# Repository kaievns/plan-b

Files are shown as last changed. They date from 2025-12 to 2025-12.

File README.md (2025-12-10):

# Plan B

This is a tiny opinionated PCB that has everything packed in one place for
creating split bluetooth keyboards on top of nrf52840 chip and ZMK firmware

Think about it as

- an improved nice!nano clone in a smaller package
- has baked nice!view inside with a slot for LCD
- has baked in RGB controller
- has baked in 6-pin SPI interface for external sensor
- has baked in wiring for 6x6 keyboard matrix via JST connectors
- has baked in power/reset switches for both sides
- high efficiency DC/DC buck converters for all power lines
- heavily fabrication optimised BOM and PCB (est $130 per 5 units at JLCPCB)

All in a tiny 14x42mm package, which is about 8m longer than nice!view shield

<p align="center">
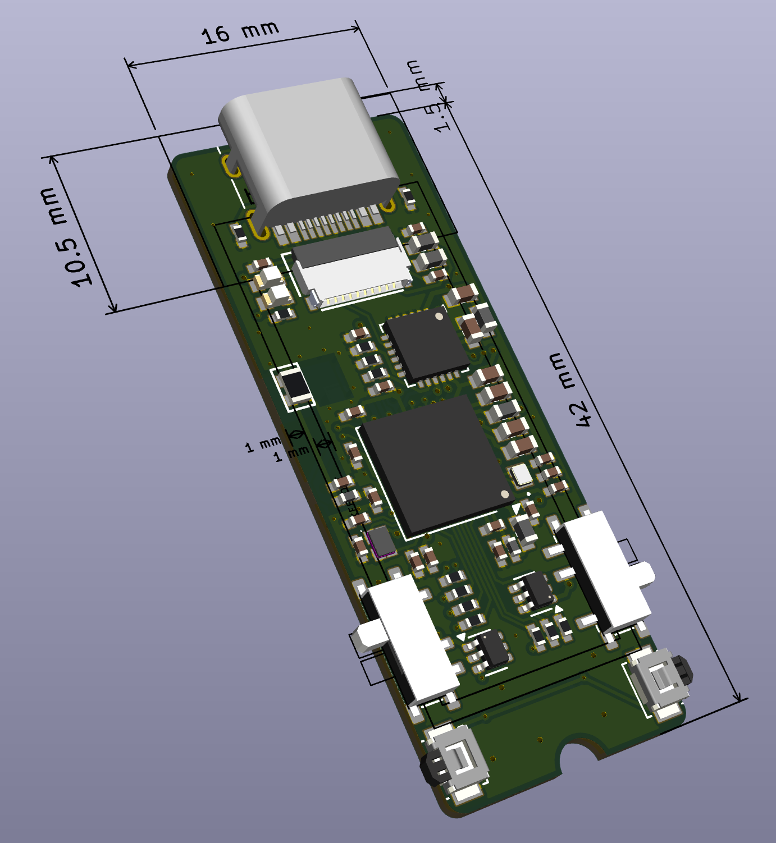
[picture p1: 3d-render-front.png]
PCB Front
  
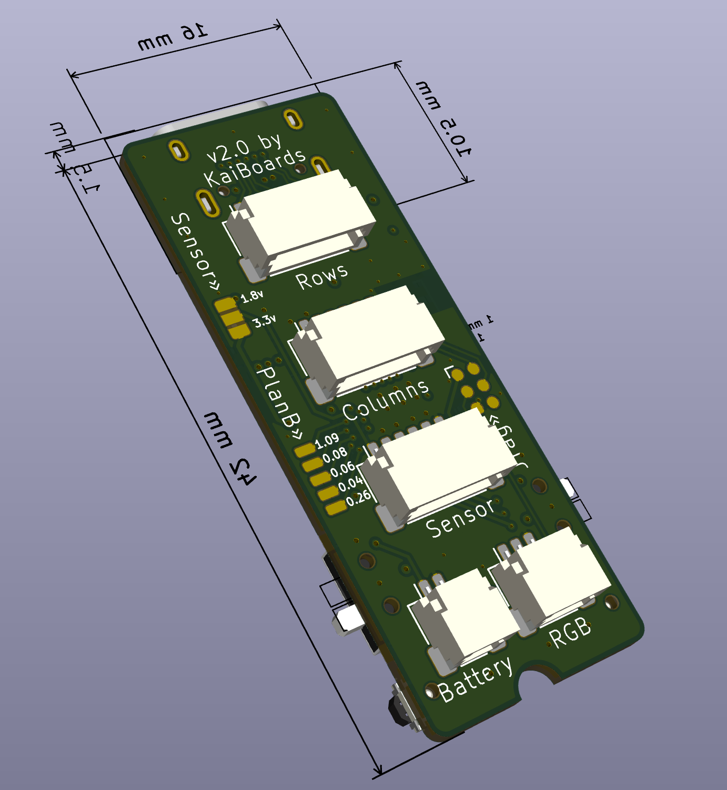
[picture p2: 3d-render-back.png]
PCB Back
  
</p>

## Copyright & License

Everything is released under the terms of the CC BY-SA 4.0 license

© 2025 Kai Evans

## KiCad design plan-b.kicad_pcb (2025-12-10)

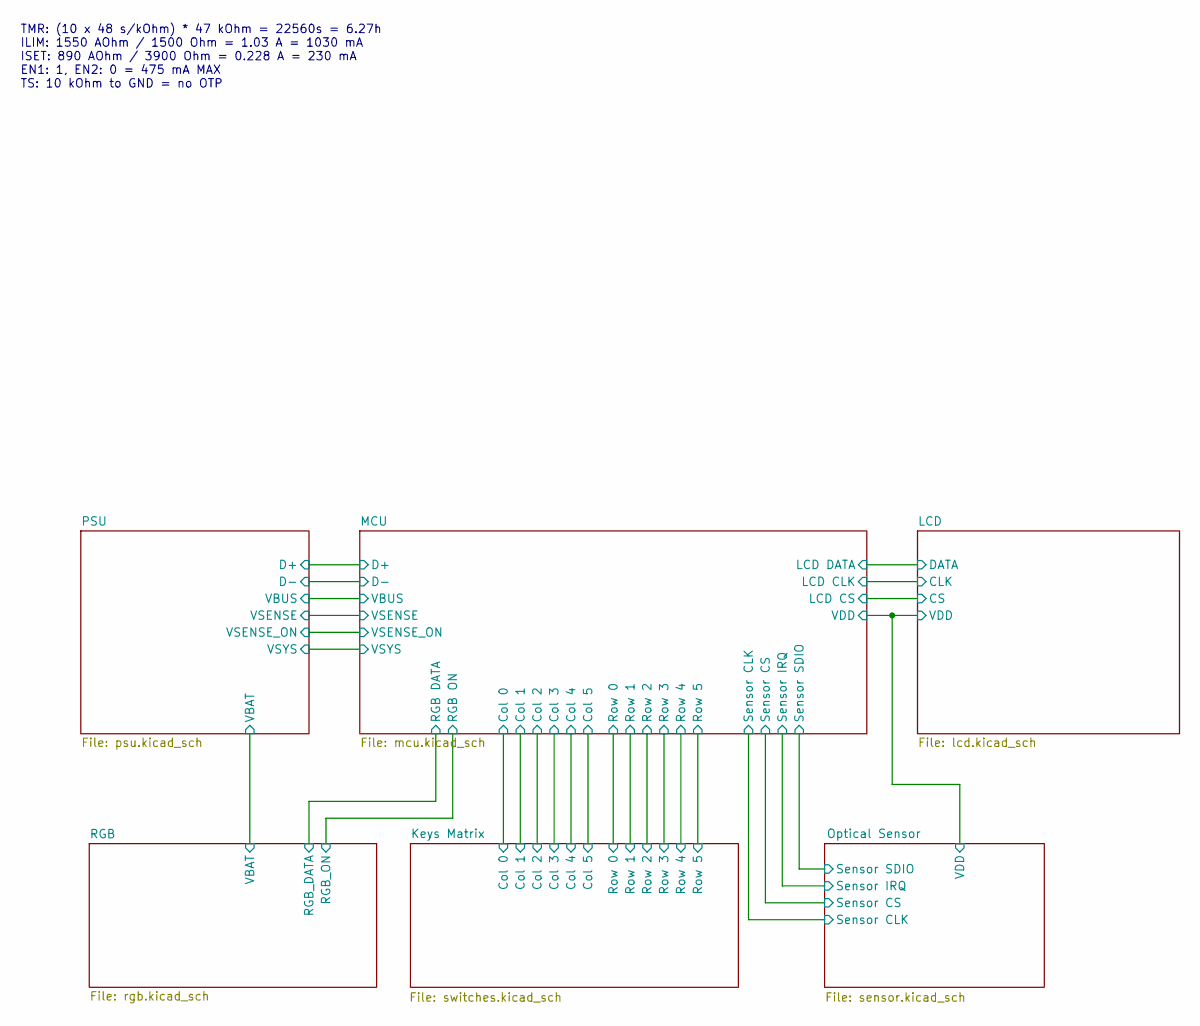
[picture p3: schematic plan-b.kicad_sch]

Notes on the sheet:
TMR: (10 x 48 s/kOhm) * 47 kOhm = 22560s = 6.27h ILIM: 1550 AOhm / 1500 Ohm = 1.03 A = 1030 mA ISET: 890 AOhm / 3900 Ohm = 0.228 A = 230 mA EN1: 1, EN2: 0 = 475 mA MAX TS: 10 kOhm to GND = no OTP

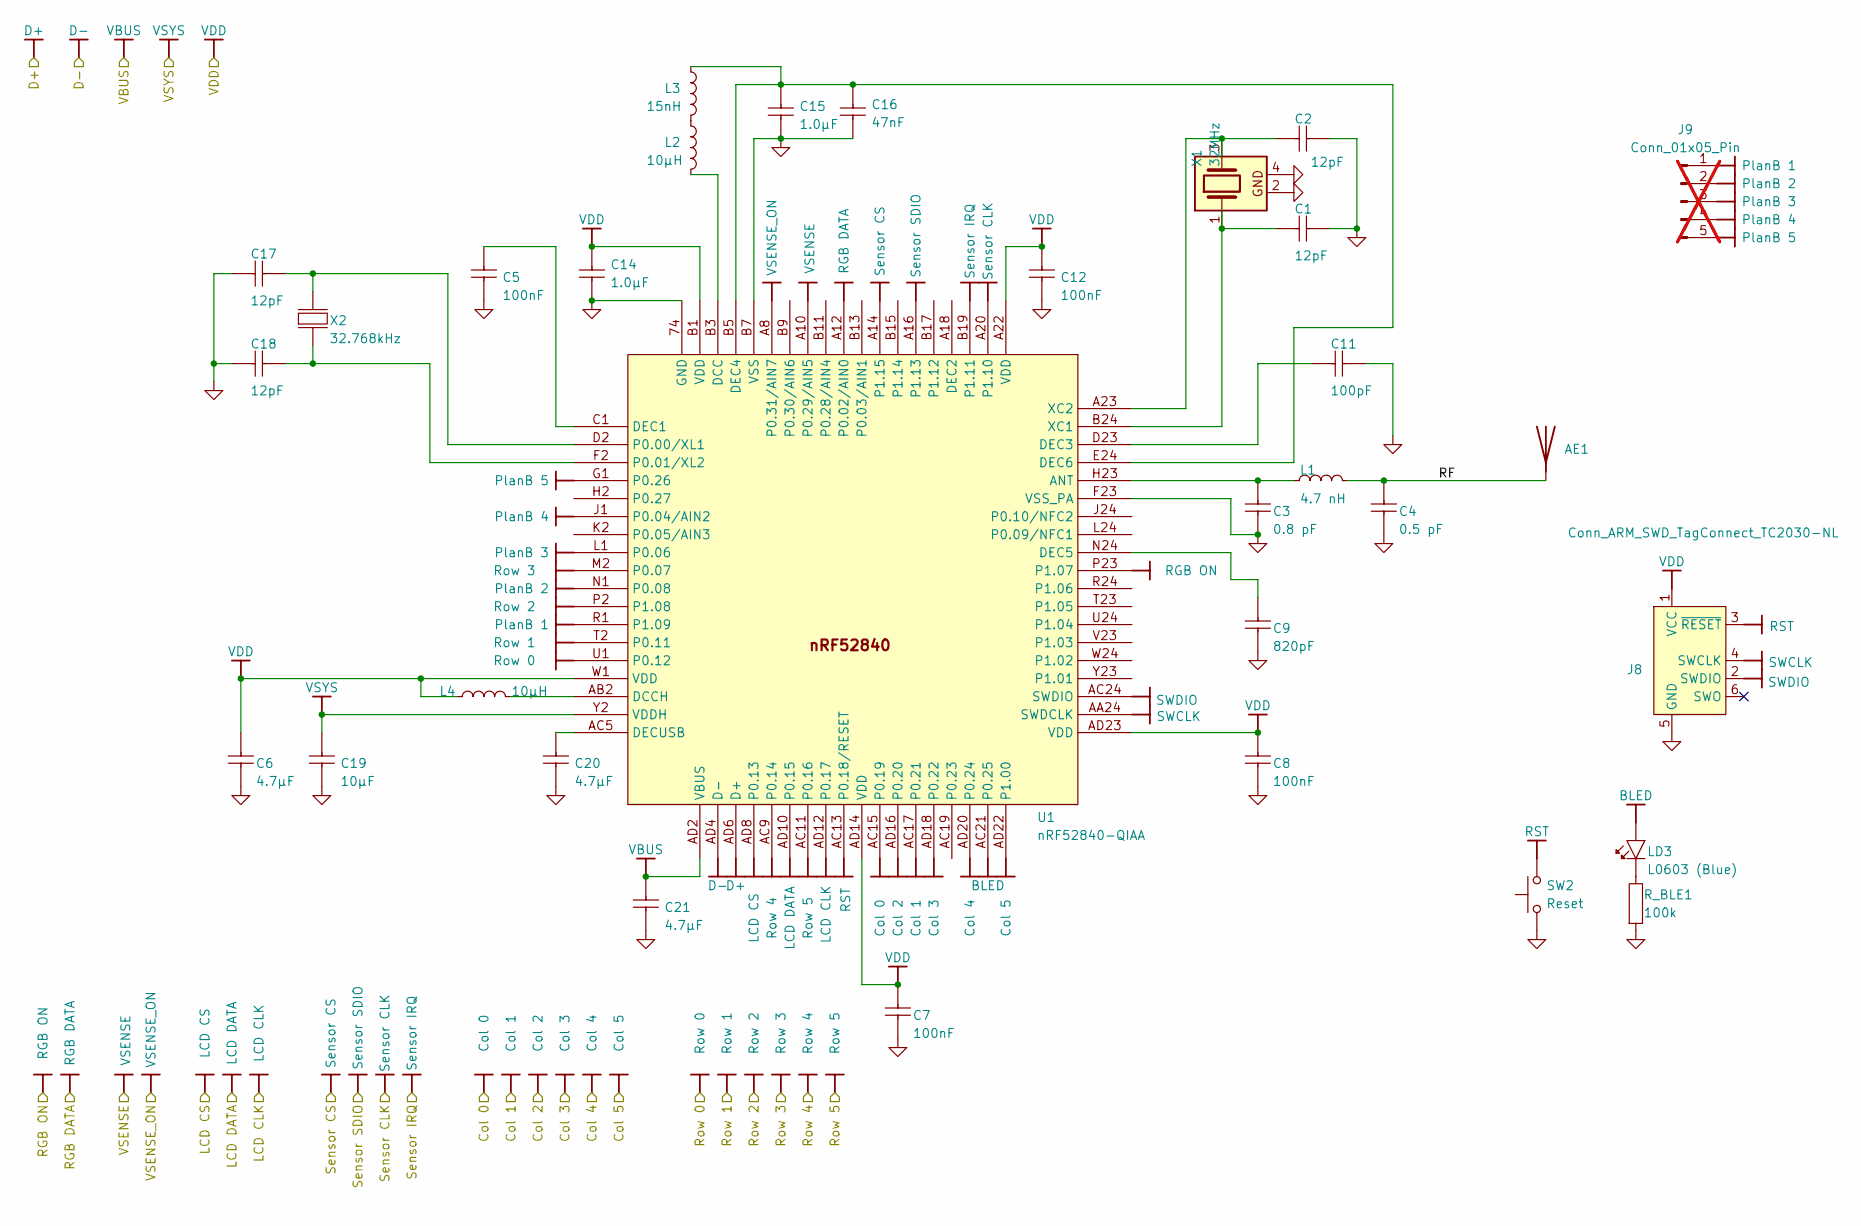
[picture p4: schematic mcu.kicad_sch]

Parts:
AE1: ANT2012LL13R2400A; PARTREV 1.3; LCSC C19192917
C1, C2, C17, C18: 12pF; C_0402_1005; PART NUMBER C0402-12p; LCSC C1547
C3: 0.8 pF; C_0402_1005; PART NUMBER C0402-0.8p; LCSC C40459
C4: 0.5 pF; C_0402_1005; PART NUMBER C0402-0.8p; LCSC C76912
C5, C7, C8, C12: 100nF; C_0402_1005; PART NUMBER C0402-100n; LCSC C1525
C6, C20: 4.7µF; C_0603_1608; PART NUMBER C0603-4µ7-6.3V-X7R; LCSC C1624
C9: 820pF; C_0402_1005; PART NUMBER C0402-100n; LCSC C107031
C11: 100pF; C_0402_1005; PART NUMBER C0402-100p; LCSC C1546
C14, C15: 1.0µF; C_0402_1005; PART NUMBER C0603-1µ0; LCSC C52923
C16: 47nF; C_0402_1005; PART NUMBER C0402-47n; LCSC C82219
C19: 10µF; C_0603_1608; PART NUMBER C0603-4µ7-10V-X7S; LCSC C19702
C21: 4.7µF; C_0603_1608; PART NUMBER C0603-4µ7-10V-X7S; LCSC C1624
J8: Conn_ARM_SWD_TagConnect_TC2030-NL; Tag-Connect_TC2030-IDC-NL_2x03_P1.27mm_Vertical
J9: Conn_01x05_Pin; JST_SHL_SM05B-SHLS-TF_1x05-1MP_P1.00mm_Horizontal; not fitted
L1: 4.7 nH; L_0402_1005; PART NUMBER L0402-4n7; LCSC C86065
L2, L4: 10µH; L_0603_1608; PART NUMBER L0603-10µ; LCSC C1035
L3: 15nH; L_0402_1005; PART NUMBER L0402-15n; LCSC C86059
LD3: L0603 (Blue); LED_0603_1608; LCSC C84266
R_BLE1: 100k; R_0402_1005; LCSC C25741
SW2: Reset; SW_SPST_B3U-3000P-B; LCSC C963349
U1: nRF52840-QIAA; Nordic_AQFN-73-1EP_7x7mm_P0.5mm; PART NUMBER nRF52840-QIAA; LCSC C1851953
X1: 32MHz; OSCSC105P160X120X35-4N; PART NUMBER XTAL_SMD2016_32MHz_8pF_General; LCSC C910049
X2: 32.768kHz; XTAL_ECS32761210TR; PART NUMBER XTAL_SMD3215_32.768kHz_9pF_General; LCSC C5682932

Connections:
/MCU/RF: AE1.1 (A), C4.2, L1.2
BLED: LD3.2 (A), U1.AC21 (P0.25)
CLK: U1.AD12 (P0.17); also elsewhere on the board
CS: U1.AD8 (P0.13); also elsewhere on the board
Col 0: U1.AC15 (P0.19); also elsewhere on the board
Col 1: U1.AC17 (P0.21); also elsewhere on the board
Col 2: U1.AD16 (P0.20); also elsewhere on the board
Col 3: U1.AD18 (P0.22); also elsewhere on the board
Col 4: U1.AD20 (P0.24); also elsewhere on the board
Col 5: U1.AD22 (P1.00); also elsewhere on the board
D+: U1.AD6 (D+); also elsewhere on the board
D-: U1.AD4 (D-); also elsewhere on the board
DATA: U1.AD10 (P0.15); also elsewhere on the board
GND: C1.2, C2.2, C3.1, C4.1, C5.2, C6.2, C7.2, C8.2, C9.2, C11.2, C12.2, C14.2, C15.1, C16.2, C17.2, C18.2, C19.2, C20.2, C21.2, J8.5 (GND), R_BLE1.2, SW2.1, U1.74 (GND), U1.B7 (VSS), U1.F23 (VSS_PA), X1.2, X1.4; also elsewhere on the board
unnamed: L2.1, L3.2
unnamed: LD3.1 (C), R_BLE1.1
unnamed: C3.2, L1.1, U1.H23 (ANT)
unnamed: L2.2, U1.B3 (DCC)
unnamed: L4.2, U1.AB2 (DCCH)
unnamed: C5.1, U1.C1 (DEC1)
unnamed: C11.1, U1.D23 (DEC3)
unnamed: C15.2, C16.1, L3.1, U1.B5 (DEC4), U1.E24 (DEC6)
unnamed: C9.1, U1.N24 (DEC5)
unnamed: C20.1, U1.AC5 (DECUSB)
unnamed: C17.1, U1.D2 (P0.00/XL1), X2.1 (inp)
unnamed: C18.1, U1.F2 (P0.01/XL2), X2.2 (out)
unnamed: C1.1, U1.B24 (XC1), X1.1
unnamed: C2.1, U1.A23 (XC2), X1.3
PlanB 1: J9.1, U1.R1 (P1.09)
PlanB 2: J9.2, U1.N1 (P0.08)
PlanB 3: J9.3, U1.L1 (P0.06)
PlanB 4: J9.4, U1.J1 (P0.04/AIN2)
PlanB 5: J9.5, U1.G1 (P0.26)
RGB DATA: U1.A12 (P0.02/AIN0); also elsewhere on the board
RGB ON: U1.P23 (P1.07); also elsewhere on the board
RST: J8.3 (~RESET), SW2.2, U1.AC13 (P0.18/RESET); also elsewhere on the board
Row 0: U1.U1 (P0.12); also elsewhere on the board
Row 1: U1.T2 (P0.11); also elsewhere on the board
Row 2: U1.P2 (P1.08); also elsewhere on the board
Row 3: U1.M2 (P0.07); also elsewhere on the board
Row 4: U1.AC9 (P0.14); also elsewhere on the board
Row 5: U1.AC11 (P0.16); also elsewhere on the board
SWCLK: J8.4 (SWCLK), U1.AA24 (SWDCLK)
SWDIO: J8.2 (SWDIO), U1.AC24 (SWDIO)
Sensor CLK: U1.A20 (P1.10); also elsewhere on the board
Sensor CS: U1.A14 (P1.15); also elsewhere on the board
Sensor IRQ: U1.B19 (P1.11); also elsewhere on the board
Sensor SDIO: U1.A16 (P1.13); also elsewhere on the board
VBUS: C21.1, U1.AD2 (VBUS); also elsewhere on the board
VDD: C6.1, C7.1, C8.1, C12.1, C14.1, J8.1 (VCC), L4.1, U1.A22 (VDD), U1.AD14 (VDD), U1.AD23 (VDD), U1.B1 (VDD), U1.W1 (VDD); also elsewhere on the board
VSENSE: U1.A10 (P0.29/AIN5); also elsewhere on the board
VSENSE_ON: U1.A8 (P0.31/AIN7); also elsewhere on the board
VSYS: C19.1, U1.Y2 (VDDH); also elsewhere on the board

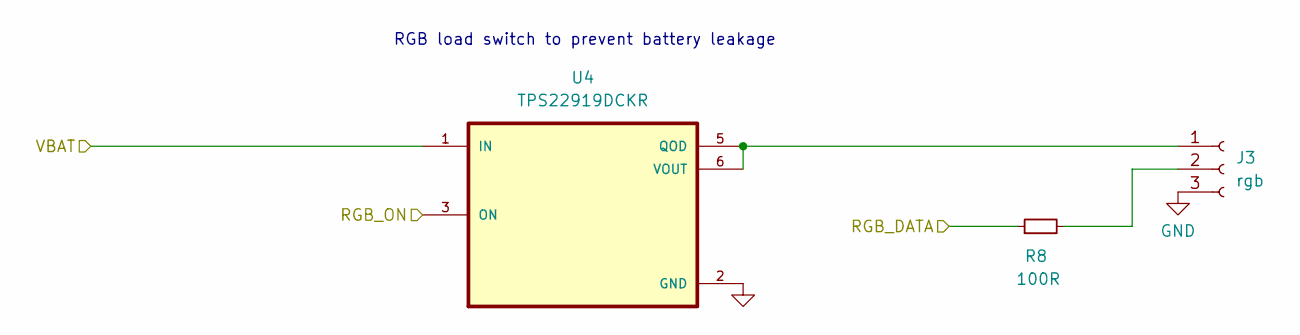
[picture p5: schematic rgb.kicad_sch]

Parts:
J3: rgb; JST_SH_SM03B-SRSS-TB_1x03-1MP_P1.00mm_Horizontal; LCSC C160403
R8: 100R; R_0402_1005; LCSC C25076
U4: TPS22919DCKR; SOT-363_SC-70-6; LCSC C2149796

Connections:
GND: J3.3, U4.2 (GND); also elsewhere on the board
unnamed: J3.1, U4.5 (QOD), U4.6 (VOUT)
unnamed: J3.2, R8.2
RGB DATA: R8.1; also elsewhere on the board
RGB ON: U4.3 (ON); also elsewhere on the board
VBAT: U4.1 (IN); also elsewhere on the board

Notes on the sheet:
RGB load switch to prevent battery leakage

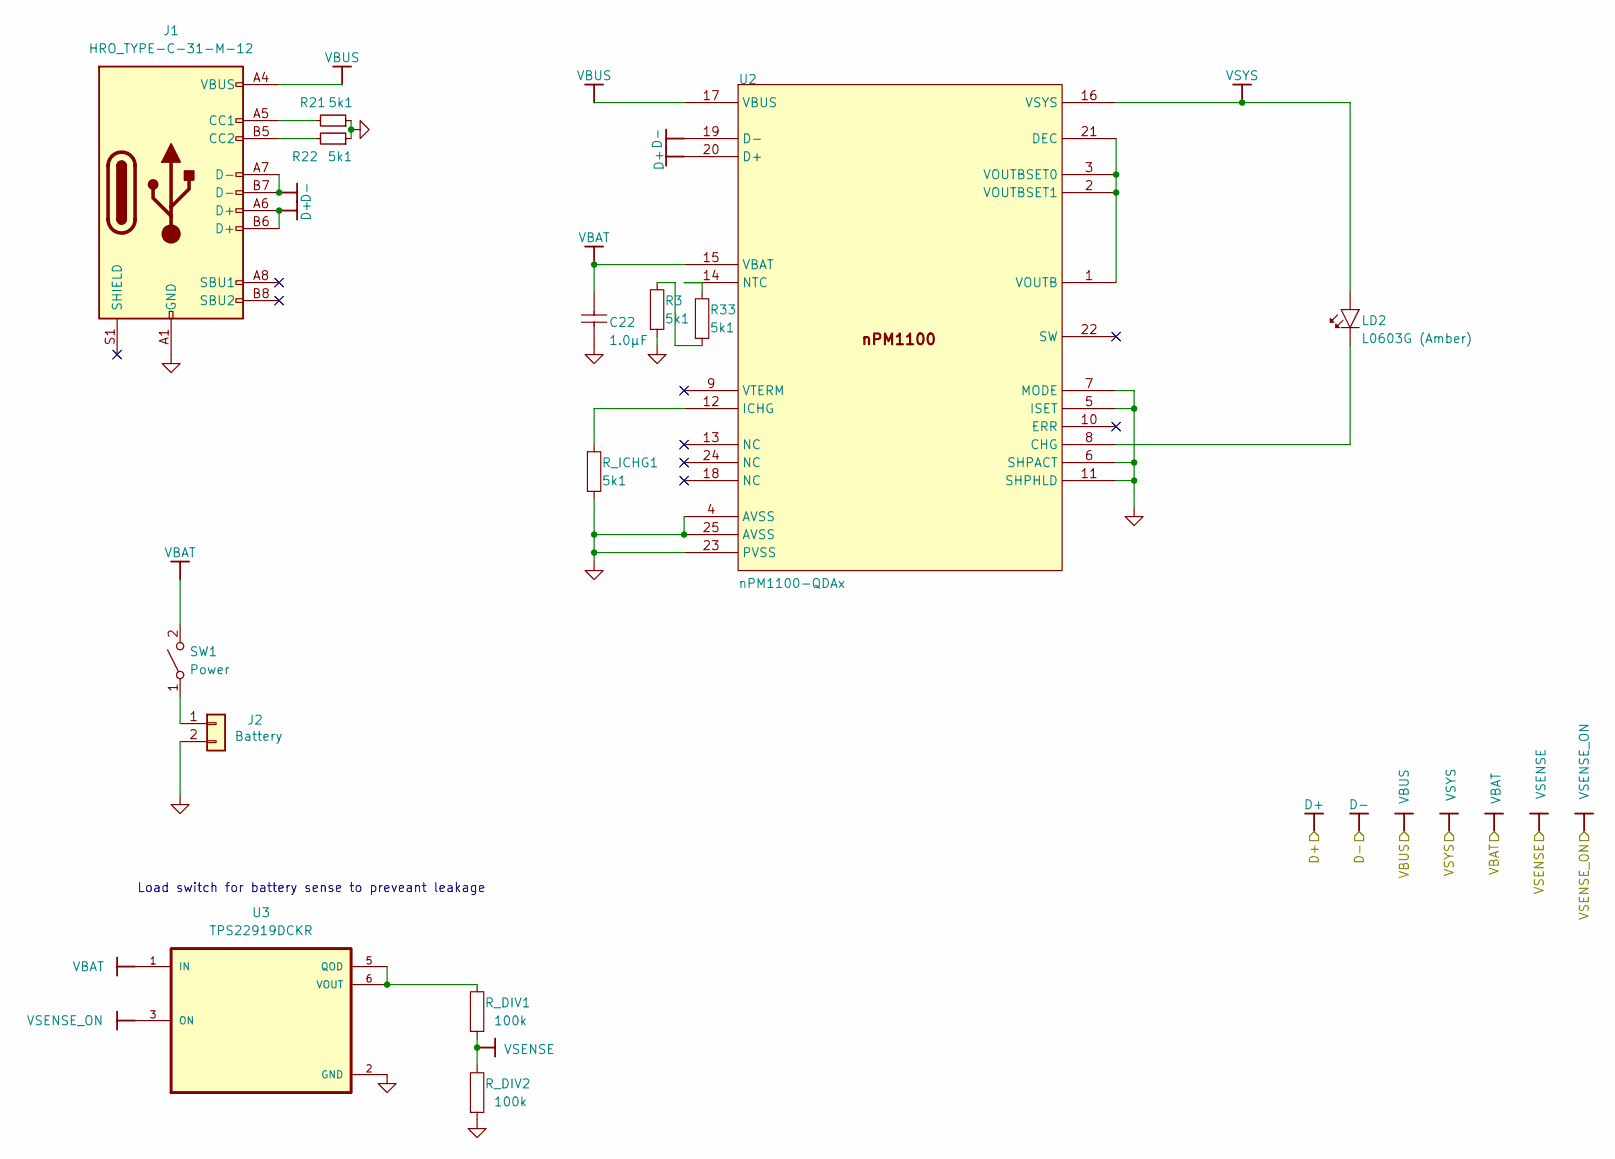
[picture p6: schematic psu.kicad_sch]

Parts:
C22: 1.0µF; C_0402_1005; LCSC C52923
J1: HRO_TYPE-C-31-M-12; USB_C_Receptacle_HRO_TYPE-C-31-M-12; LCSC C165948
J2: Battery; JST_SH_SM02B-SRSS-TB_1x02-1MP_P1.00mm_Horizontal; LCSC C160402
LD2: L0603G (Amber); LED_0603_1608; LCSC C84269
R3, R21, R22, R33: 5k1; R_0402_1005; LCSC C25905
R_DIV1, R_DIV2: 100k; R_0402_1005; LCSC C25741
R_ICHG1: 5k1; R_0402_1005; LCSC C25905
SW1: Power; Switch_MSK12C02; LCSC C431540
U2: nPM1100-QDAx; QFN-24-1EP_4x4mm_P0.5mm_EP2.6x2.6mm_ThermalVias; PART NUMBER nRF52840-QIAA; LCSC C5816773
U3: TPS22919DCKR; SOT-363_SC-70-6; LCSC C2149796

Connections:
D+: J1.A6 (D+), J1.B6 (D+), U2.20 (D+); also elsewhere on the board
D-: J1.A7 (D-), J1.B7 (D-), U2.19 (D-); also elsewhere on the board
GND: C22.1, J1.A1 (GND), J1.A12 (GND), J1.B1 (GND), J1.B12 (GND), J2.2, R3.2, R21.1, R22.1, R_DIV2.2, R_ICHG1.1, U2.4 (AVSS), U2.5 (ISET), U2.6 (SHPACT), U2.7 (MODE), U2.11 (SHPHLD), U2.23 (PVSS), U2.25 (AVSS), U3.2 (GND); also elsewhere on the board
unnamed: J1.A5 (CC1), R21.2
unnamed: J1.B5 (CC2), R22.2
unnamed 17: J2.1, SW1.1 (A); also elsewhere on the board
unnamed: LD2.1 (C), U2.8 (CHG)
unnamed: R3.1, R33.2
unnamed: U2.1 (VOUTB), U2.2 (VOUTBSET1), U2.3 (VOUTBSET0), U2.21 (DEC)
unnamed: R_ICHG1.2, U2.12 (ICHG)
unnamed: R33.1, U2.14 (NTC)
unnamed: R_DIV1.1, U3.5 (QOD), U3.6 (VOUT)
VBAT: C22.2, SW1.2 (B), U2.15 (VBAT), U3.1 (IN); also elsewhere on the board
VBUS: J1.A4 (VBUS), J1.A9 (VBUS), J1.B4 (VBUS), J1.B9 (VBUS), U2.17 (VBUS); also elsewhere on the board
VSENSE: R_DIV1.2, R_DIV2.1; also elsewhere on the board
VSENSE_ON: U3.3 (ON); also elsewhere on the board
VSYS: LD2.2 (A), U2.16 (VSYS); also elsewhere on the board

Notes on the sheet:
Load switch for battery sense to preveant leakage

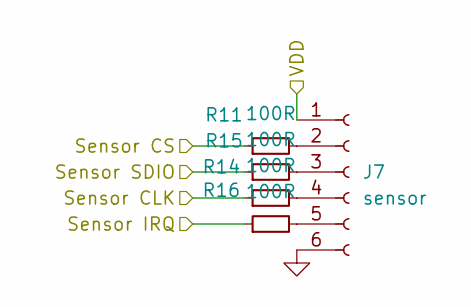
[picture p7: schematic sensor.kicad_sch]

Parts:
J7: sensor; JST_SH_SM06B-SRSS-TB_1x06-1MP_P1.00mm_Horizontal; LCSC C160405
R11, R14, R15, R16: 100R; R_0402_1005; LCSC C25076

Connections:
GND: J7.6; also elsewhere on the board
unnamed: J7.2, R11.2
unnamed: J7.3, R14.2
unnamed: J7.4, R15.2
unnamed: J7.5, R16.2
Sensor CLK: R15.1; also elsewhere on the board
Sensor CS: R11.1; also elsewhere on the board
Sensor IRQ: R16.1; also elsewhere on the board
Sensor SDIO: R14.1; also elsewhere on the board
VDD: J7.1; also elsewhere on the board

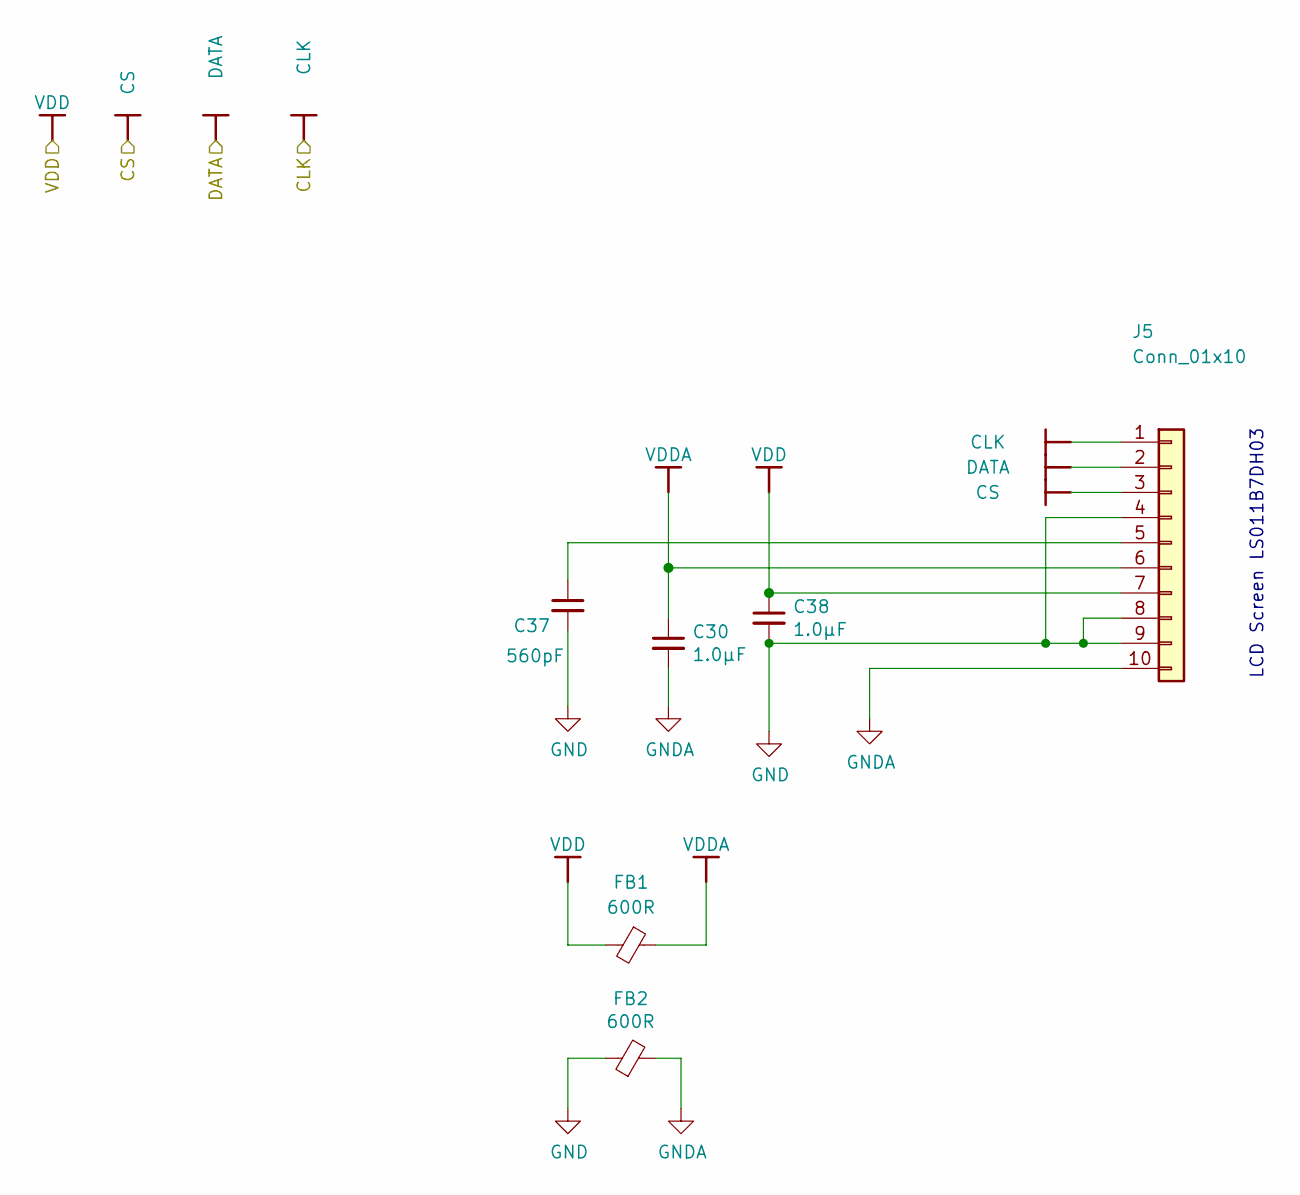
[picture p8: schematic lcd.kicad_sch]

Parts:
C30, C38: 1.0µF; C_0402_1005; LCSC C52923
C37: 560pF; C_0402_1005; LCSC C1539
FB1, FB2: 600R; F_0603_1608; LCSC C1002
J5: Conn_01x10; CONN10x1_FH34SRJ-10S-0.5SH50_HIR; LCSC C324723

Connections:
CLK: J5.1; also elsewhere on the board
CS: J5.3; also elsewhere on the board
DATA: J5.2; also elsewhere on the board
GND: C37.2, C38.2, FB2.1, J5.4, J5.8, J5.9; also elsewhere on the board
GNDA: C30.2, FB2.2, J5.10
unnamed: C37.1, J5.5
VDD: C38.1, FB1.2, J5.7; also elsewhere on the board
VDDA: C30.1, FB1.1, J5.6

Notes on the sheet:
LCD Screen LS011B7DH03

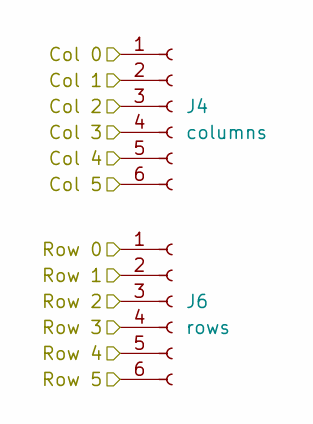
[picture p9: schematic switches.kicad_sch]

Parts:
J4: columns; JST_SH_SM06B-SRSS-TB_1x06-1MP_P1.00mm_Horizontal; LCSC C160405
J6: rows; JST_SH_SM06B-SRSS-TB_1x06-1MP_P1.00mm_Horizontal; LCSC C160405

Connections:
Col 0: J4.1; also elsewhere on the board
Col 1: J4.2; also elsewhere on the board
Col 2: J4.3; also elsewhere on the board
Col 3: J4.4; also elsewhere on the board
Col 4: J4.5; also elsewhere on the board
Col 5: J4.6; also elsewhere on the board
Row 0: J6.1; also elsewhere on the board
Row 1: J6.2; also elsewhere on the board
Row 2: J6.3; also elsewhere on the board
Row 3: J6.4; also elsewhere on the board
Row 4: J6.5; also elsewhere on the board
Row 5: J6.6; also elsewhere on the board

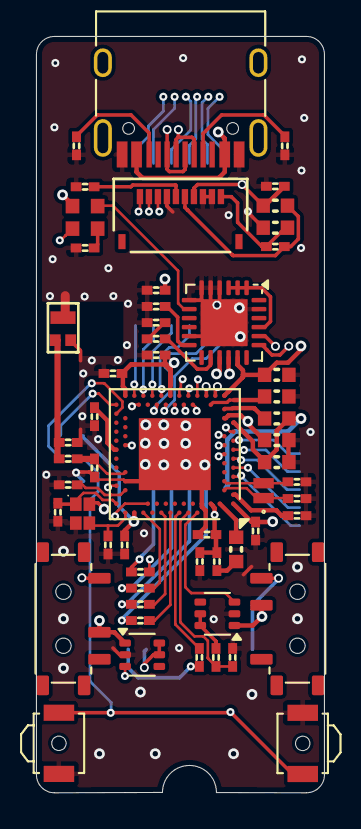
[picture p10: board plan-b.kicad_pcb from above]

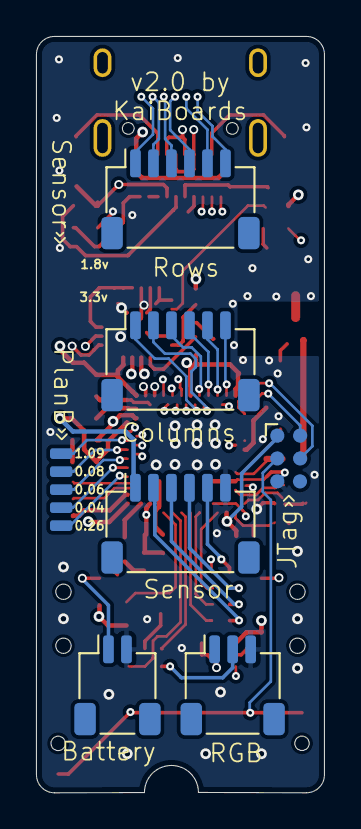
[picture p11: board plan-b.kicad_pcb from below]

Board: 4 copper layers, 16.0 x 42.0 mm, 64 parts (7 on the bottom side), 72 nets.

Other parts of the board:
SW1#2: Power; Switch_MSK12C02
SW2#2: Reset; SW_SPST_B3U-3000P-B

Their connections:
GND: SW2#2.1; also elsewhere on the board
unnamed 17: SW1#2.1 (A); also elsewhere on the board
RST: SW2#2.2; also elsewhere on the board
VBAT: SW1#2.2 (B); also elsewhere on the board

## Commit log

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2025-01-18 Splitting the KiCAD project into thre independent PCBs
    [mobo.kicad_pcb, mobo.kicad_sch]
2025-03-28 Resetting the mobo stack to 4 layers mirrorable
    [mobo.kicad_pcb, mobo.kicad_sch]
2025-03-29 Reworking the mobo into a reversible panel
    [mobo.kicad_pcb]
2025-03-29 Reworking the keypad PCB
    [mobo.kicad_pcb]
2025-09-24 Dumping everything i need into the combined schematic
    [mobo.kicad_sch]
2025-09-27 Cleaning up the schematics
    [mobo.kicad_pcb, mobo.kicad_sch]
2025-09-27 Resetting the PCB
    [mobo.kicad_pcb]
2025-09-27 Replacing the through holes with JST-SH connectors
    [mobo.kicad_pcb, mobo.kicad_sch]
2025-10-07 Adding connectors 3d files
    [mobo.kicad_pcb]
2025-10-11 Assigning all the perifery pins
    [mobo.kicad_pcb, mobo.kicad_sch]
2025-10-11 Groupping around the PCB components
    [mobo.kicad_pcb]
2025-10-12 Loosely optimising the groups components placement
    [mobo.kicad_pcb, mobo.kicad_sch]
2025-10-12 Groupping the groups into a workable arrangement
    [mobo.kicad_pcb]
2025-10-12 Sub-compacting the components to their target dimensions
    [mobo.kicad_pcb]
2025-10-12 Partially wiring the bottom half
    [mobo.kicad_pcb]
2025-11-07 Importing reference schematics for nrf52840 and npm1100 chips and renaming the project
    [little-wing.kicad_pcb, little-wing.kicad_sch, mcu.kicad_sch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]
2025-11-07 Re-shuffling the schematics across sub-sheets
    [io.kicad_sch, lcd.kicad_sch, little-wing.kicad_sch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]
2025-11-07 Copying over the reference PCB stacks
    [little-wing.kicad_pcb, little-wing.kicad_sch, sensor.kicad_sch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]
2025-11-08 Tidying up the mess a little bit
    [little-wing.kicad_pcb, little-wing.kicad_sch, mcu.kicad_sch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]
2025-11-09 Re-importing some key components
    [little-wing.kicad_pcb, mcu.kicad_sch]
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2025-11-09 Removing the NFC1/2 connectors
    [little-wing.kicad_pcb, mcu.kicad_sch]
2025-11-09 Cleaning up the PSU schematics
    [little-wing.kicad_pcb, mobo.kicad_sch, psu.kicad_sch]
2025-11-10 Cleaning up the schematics a bit more
    [io.kicad_sch, lcd.kicad_sch, mcu.kicad_sch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]
2025-11-11 Updating schematics/pcb to match the labels
    [lcd.kicad_sch, little-wing.kicad_pcb, mcu.kicad_sch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]
2025-11-12 Cleaning up some space on the PCB
    [little-wing.kicad_pcb, mcu.kicad_sch, psu.kicad_sch]
2025-11-12 Reseting all the extra components sizes
    [io.kicad_sch, lcd.kicad_sch, little-wing.kicad_pcb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]
2025-11-12 Dissolving and re-packaging the PSU block
    [little-wing.kicad_pcb]
2025-11-12 Unshielding the main block
    [little-wing.kicad_pcb]
2025-11-12 Swapping the crystals for smaller ones
    [io.kicad_sch, little-wing.kicad_pcb, mcu.kicad_sch]
2025-11-13 Dialing in the physical package
    [io.kicad_sch, little-wing.kicad_pcb, mcu.kicad_sch]
2025-11-13 Putting all the components in their rough places
    [little-wing.kicad_pcb]
2025-11-14 Backporting footprints from the PCB back to schematic
    [lcd.kicad_sch, little-wing.kicad_pcb, mcu.kicad_sch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]
2025-11-14 Fixes and space optimisations
    [little-wing.kicad_pcb, mcu.kicad_sch, mobo.kicad_sch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]
2025-11-15 Loosely attaching pins to prefiery
    [io.kicad_sch, little-wing.kicad_pcb, mcu.kicad_sch]
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2025-11-15 Connecting most of the other components
    [little-wing.kicad_pcb]
2025-11-16 Connecting remaining power lines
    [io.kicad_sch, little-wing.kicad_pcb, mcu.kicad_sch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]
2025-11-16 Adding the J-tag connector for the programmer
    [little-wing.kicad_pcb, mcu.kicad_sch]
2025-11-16 Adding the solid ground fill
    [little-wing.kicad_pcb]
2025-11-17 Adding the Plan B pins
    [little-wing.kicad_pcb, mcu.kicad_sch]
2025-11-17 Re-organising the schematics sheets a bit
    [io.kicad_sch, lcd.kicad_sch, little-wing.kicad_sch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]
2025-11-18 Reworking the RGB power section
    [little-wing.kicad_pcb, little-wing.kicad_sch, rgb.kicad_sch]
2025-11-19 Moving the RGB feed capacitor
    [little-wing.kicad_pcb, rgb.kicad_sch]
2025-11-23 Removing the RGB level shifter
    [little-wing.kicad_pcb, little-wing.kicad_sch, mcu.kicad_sch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]
2025-11-23 Renaming the project and throwing a read-me
    [plan-b.kicad_pcb, plan-b.kicad_sch]
2025-11-25 Reworking the PSU schematic to QDA package, adding DC/DC 1.8v source for optical sensor, and load switch for the battery sensor to prevent leakage
    [plan-b.kicad_sch, psu.kicad_sch]
2025-11-25 Swapping the load switches from WLSP to WSON-6 packages
    [psu.kicad_sch, rgb.kicad_sch]
2025-11-25 Reworking the MCU schematics sheet into QIAA package
    [mcu.kicad_sch, plan-b.kicad_sch]
2025-11-27 Dumping the reference layouts into the PCB
    [mcu.kicad_sch, plan-b.kicad_pcb, plan-b.kicad_sch]
2025-11-28 Adding some basic libarary components
    [plan-b.kicad_pcb]
2025-11-29 Cleaning up more components
    [mcu.kicad_sch, plan-b.kicad_pcb, psu.kicad_sch]
2025-11-29 Relinking the schematics and the PCB again
    [plan-b.kicad_pcb, psu.kicad_sch, rgb.kicad_sch]
2025-11-29 Setting up the RF/Antenna setup
    [plan-b.kicad_pcb]
2025-11-29 Tidying up the PSU block
    [plan-b.kicad_pcb, psu.kicad_sch]
2025-11-29 Switching to smaller crystalls
    [plan-b.kicad_pcb]
2025-11-29 Sorting out the remaining components footprints and rough positioning
    [plan-b.kicad_pcb]
2025-11-30 Cleaning up the LCD schematics
    [lcd.kicad_sch, plan-b.kicad_pcb]
2025-11-30 Roughly aligning back and front
    [plan-b.kicad_pcb]
2025-11-30 Optimising the RF side
    [plan-b.kicad_pcb]
2025-12-01 Re-working the PCB cutouts to 16x42mm dimensions and realigning switches and connectors at the back
    [plan-b.kicad_pcb]
2025-12-01 Trying the 18x42mm form factor
    [plan-b.kicad_pcb]
2025-12-01 Moving the main block in place
    [plan-b.kicad_pcb]
2025-12-02 Re-linking the PCB properties back to the schematics
    [lcd.kicad_sch, mcu.kicad_sch, psu.kicad_sch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]
2025-12-04 Compacting the right side of the PCB
    [plan-b.kicad_pcb]
2025-12-05 Reworking the PSU block and squeeshing everything into 16x42mm space
    [mcu.kicad_sch, plan-b.kicad_pcb, psu.kicad_sch]
2025-12-05 Cleaning up the sensor signals routing
    [mcu.kicad_sch, plan-b.kicad_pcb]
2025-12-05 Wiring up the load swiches side of the PCB
    [mcu.kicad_sch, plan-b.kicad_pcb, rgb.kicad_sch]
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2025-12-06 Sorting out other pads and sensor voltage jumper
    [mcu.kicad_sch, plan-b.kicad_pcb]
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2025-12-06 Swapping rows connector to the same 6 pins as columns
    [mcu.kicad_sch, plan-b.kicad_pcb, plan-b.kicad_sch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]
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2025-12-08 Further optimising the BOM and adding JLCPCB specific part numbers
    [lcd.kicad_sch, mcu.kicad_sch, plan-b.kicad_pcb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]
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
